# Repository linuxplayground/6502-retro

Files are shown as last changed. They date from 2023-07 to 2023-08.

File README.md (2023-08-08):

# 6502-Retro!

Inspired by the Z80-Retro! see: [https://github.com/z80-retro](https://github.com/z80-retro)
I decided to see if I could put together a small 6502 based project with a similar
design philosphy.  The main goals of the project are:

1. The base board must be no larger than 100mm x 100mm to leverage the cheaper
    manufacturing options.
2. The base board must provide all required functionality to be minimially operational.
3. Daughter boards will provide additional peripherals such as Graphics and Audio

## Base Board

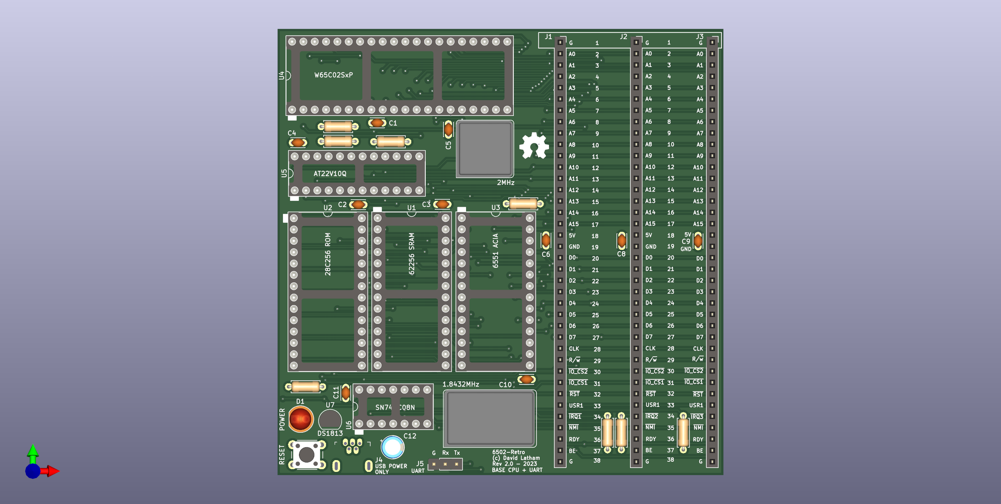
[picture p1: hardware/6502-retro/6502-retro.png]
Base Board


You can find the hardware 
[schematic](./hardware/6502-retro/6502-retro.pdf) and gerber files for the base 
board in [hardware/6502-retro](./hardware/6502-retro/).

## Expansion Boards

This project contains two expansion boards.

### NOTE !!

One of the expansion slots (J1) is too close to the BAUD RATE Oscilator on the 
base board.  It can be used for manual jumper wires maybe, but I would not risk
putting a card in there as the solder joints on the back of the card will short
against the metal oscilator can for the baud rate clock.

### F18A (TMS9918A FPGA)

The F18A from [dnotq](https://dnotq.io/f18a/intro.html) is mounted with some
glue logic on an expansion board.  It provides all the same features as the 
TMS9918A VDP along with some additional enhancments that can be accessed in
software.

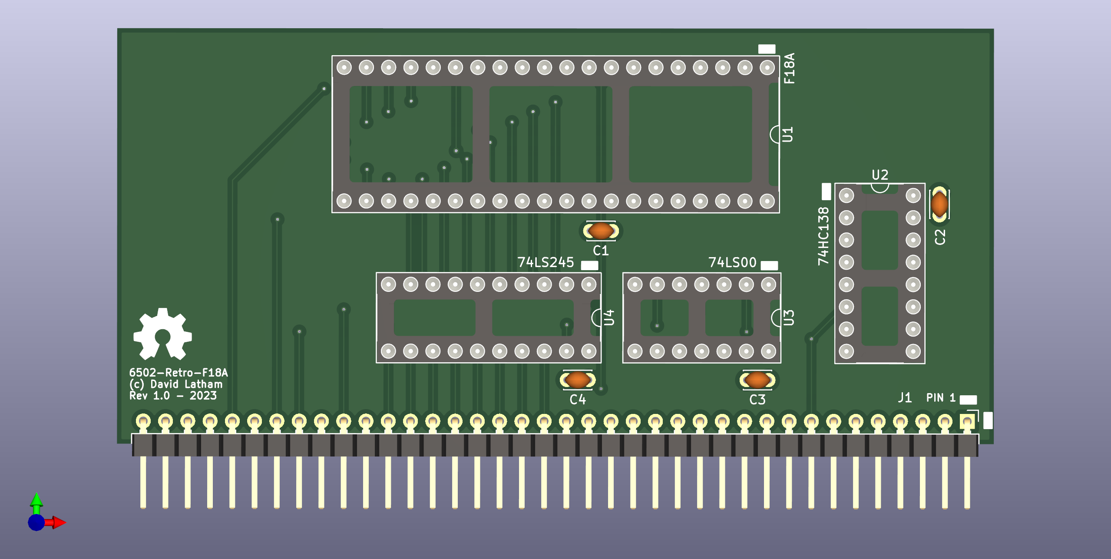
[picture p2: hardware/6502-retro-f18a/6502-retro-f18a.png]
F18A Board


You can find the hardware [schematic here.](./hardware/6502-retro-f18a/6502-retro-f18a.pdf)

### General Purpose IO + PS/2

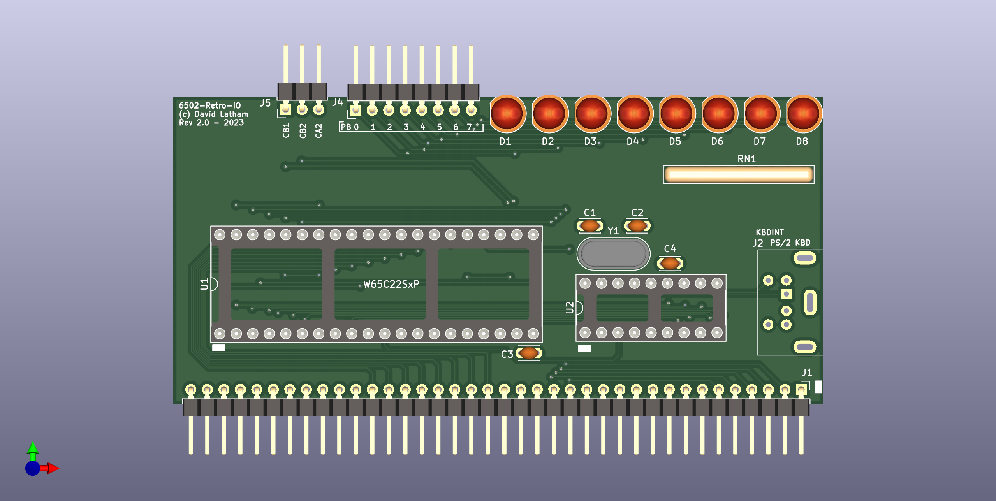
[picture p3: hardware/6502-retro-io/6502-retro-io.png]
GPIO + PS/2


You can find the hardware [schematic here.](./hardware/6502-retro-io/6502-retro-io.pdf)

Note: PS/2 Support is designed for the [PERIBOARD-409 P - Mini PS/2 keyboard](https://perixx.com/products/ps2-mini-keyboard)

This board has a "sign-on" routine that's handled in the PIC16F628A
microcontroller.  The code for the MCU is included [here](./pic16f628a/)

The more generic / standard PS/2 Keyboards will require the MCU code to be
altered.

## Memory Map

The memory map is given by an AT22v10Q PLD which provides ranges in the table below.  These values are also defined in [6502-retro-rom.cfg](./software/6502-retro-rom.cfg)

|Range |Description |Size | Decoder Pins| Comments
|--- |--- |--- |--- |---
|0000-00FF |Zero Page |0x100  | |
|0100-0200 |Stack |0x100  | |
|0200-0FFF |SYSRAM |0xE00  | |
|1000-7EFF |RAM |0x6F00 | |
| | | | |
|7F00-7F10 |UNMAPPED |0x16 | |
|7F10-7F1F |FREE |0x16 | IOCS1 + A4  | IOCS1 is clock qualified
|7F20-7F2F |ACIA |0x16 | IOCS1 + A5  |
|7F30-7F3F |UNMAPPED |0x16 | |
|7F40-7F4F |F18A / TMS9918A |0x16 | IOCS1 + A6  |
|7F50-7F8F |UNAMPPED |0x64 | |
|7F90-7F90 |VIA |0x16 | IOCS2 + A4  | IOCS2 is not clock qualified
|7FA0-7FAF |FREE |0x16 | IOCS2 + A5  |
|7FB0-7FBF |UMAPPED |0x16 | | 
|7FC0-7FCF |FREE |0x16 | IOCS2 + A6  |
|7FD0-7FEF |UNMAPPED |0x64 | |

* IOCS1 is only active when phi2 is HIGH in the shown address ranges.
* IOCS2 is active in the shown address ranges without any influence by phi2.

See the [PLD Code](./pld/6502-RETRO-PLD.PLD) for the WinCUPL design file.

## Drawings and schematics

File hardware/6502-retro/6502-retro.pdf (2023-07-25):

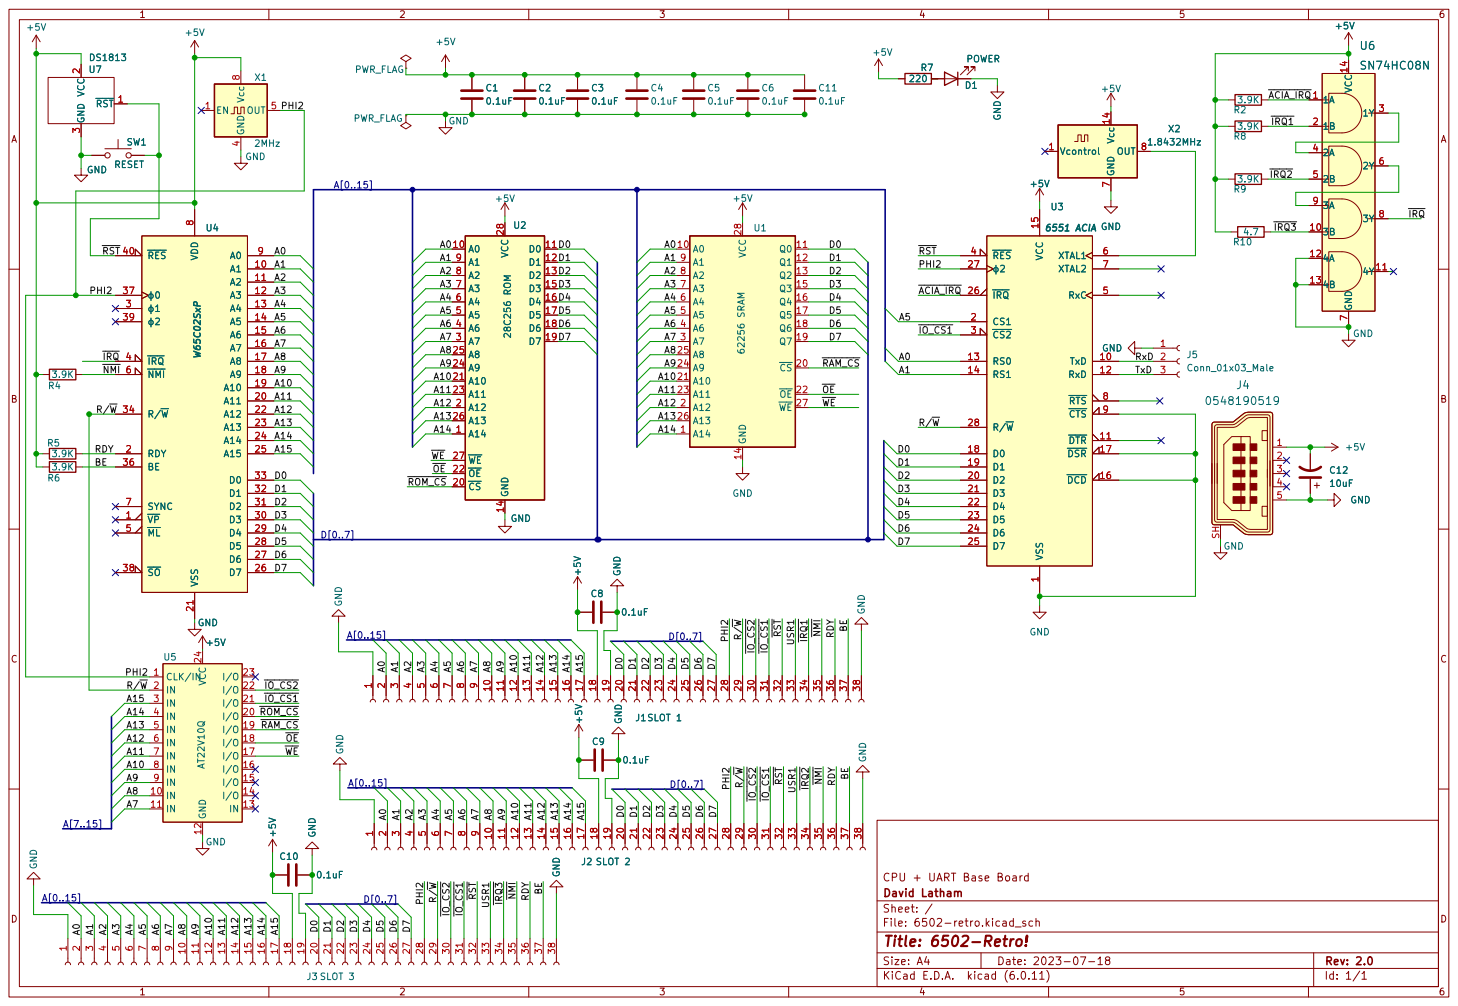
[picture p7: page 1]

CPU + UART Base Board +5V C9

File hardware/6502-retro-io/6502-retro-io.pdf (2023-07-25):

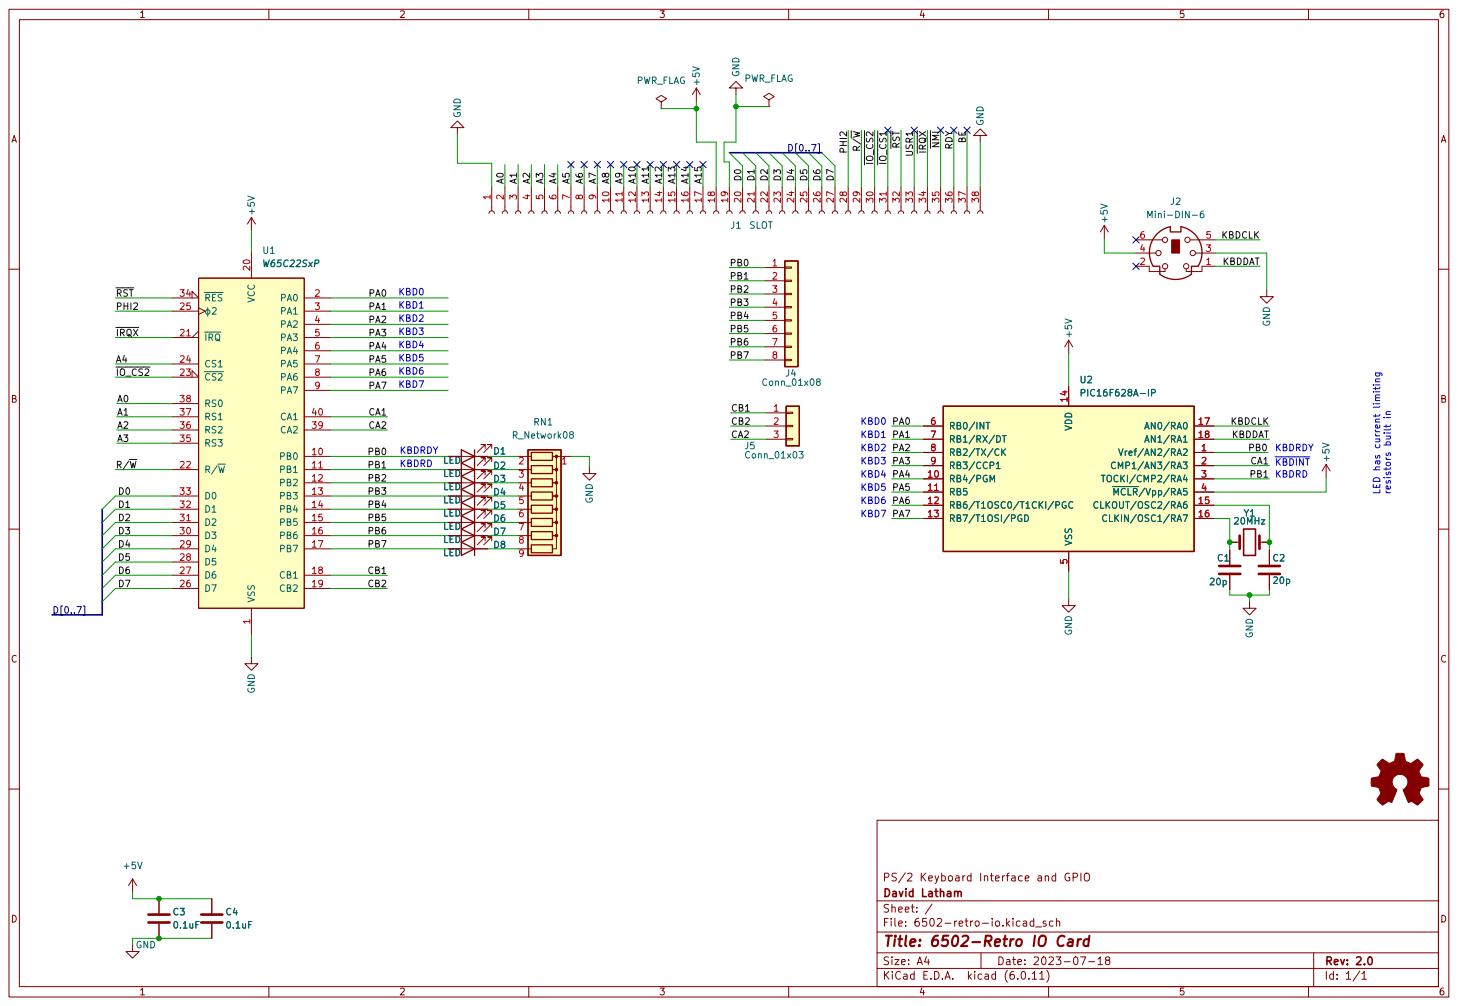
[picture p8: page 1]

5 RB0/INT 6 RB1/RX/DT 7 RB2/TX/CK 8 RB3/CCP1 9 U2PIC16F628A-IP D6

5 RB0/INT 6 RB1/RX/DT 7 RB2/TX/CK 8 RB3/CCP1 9

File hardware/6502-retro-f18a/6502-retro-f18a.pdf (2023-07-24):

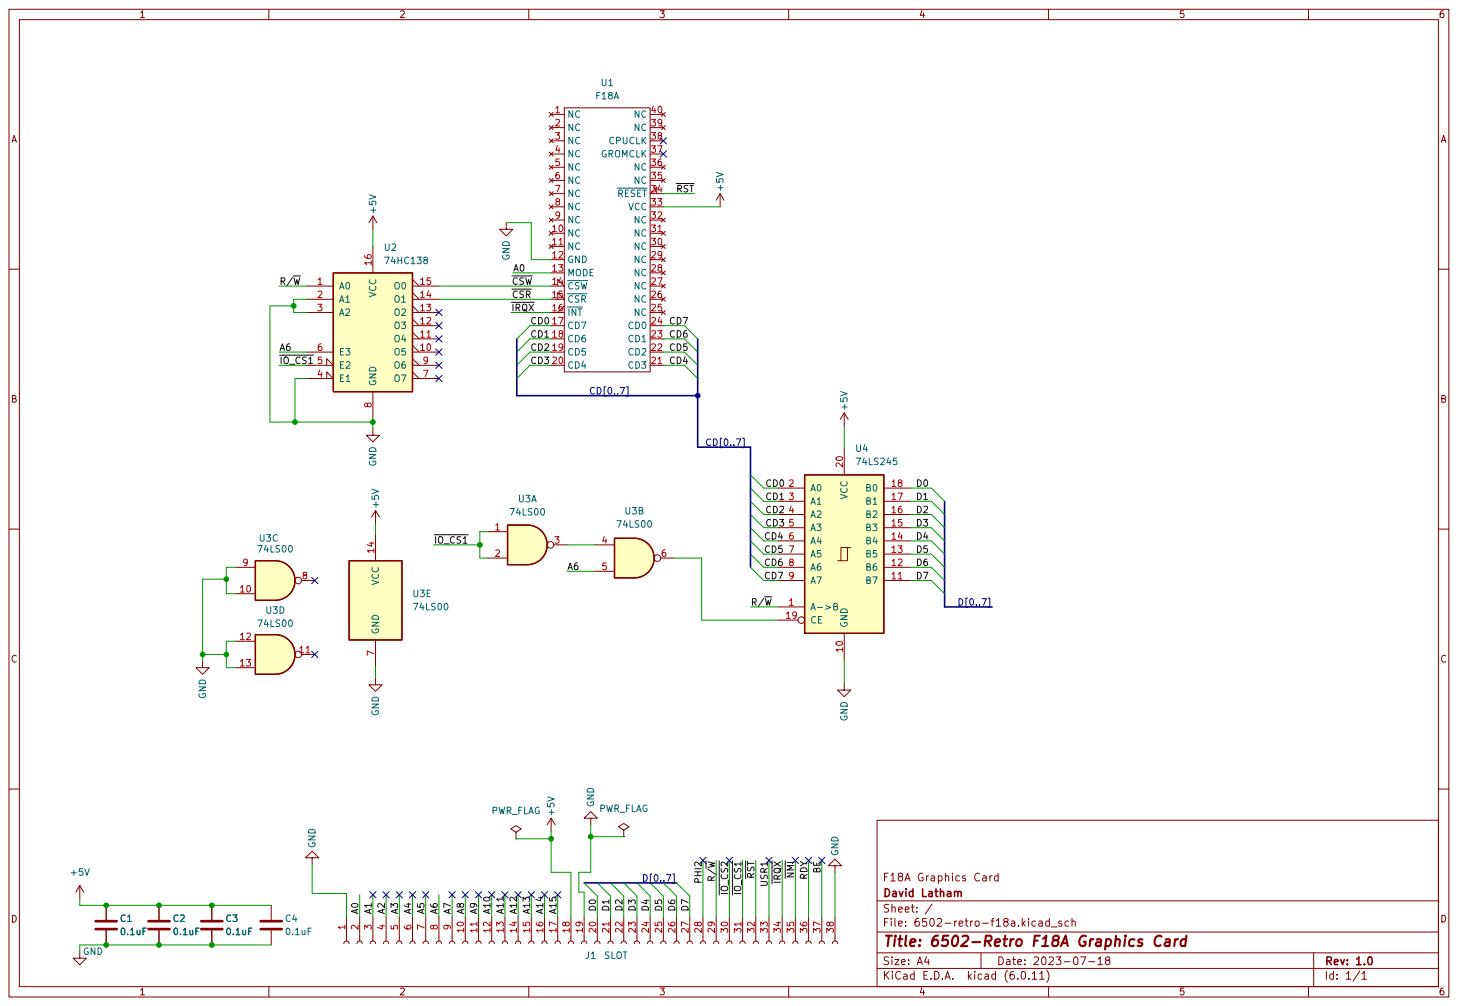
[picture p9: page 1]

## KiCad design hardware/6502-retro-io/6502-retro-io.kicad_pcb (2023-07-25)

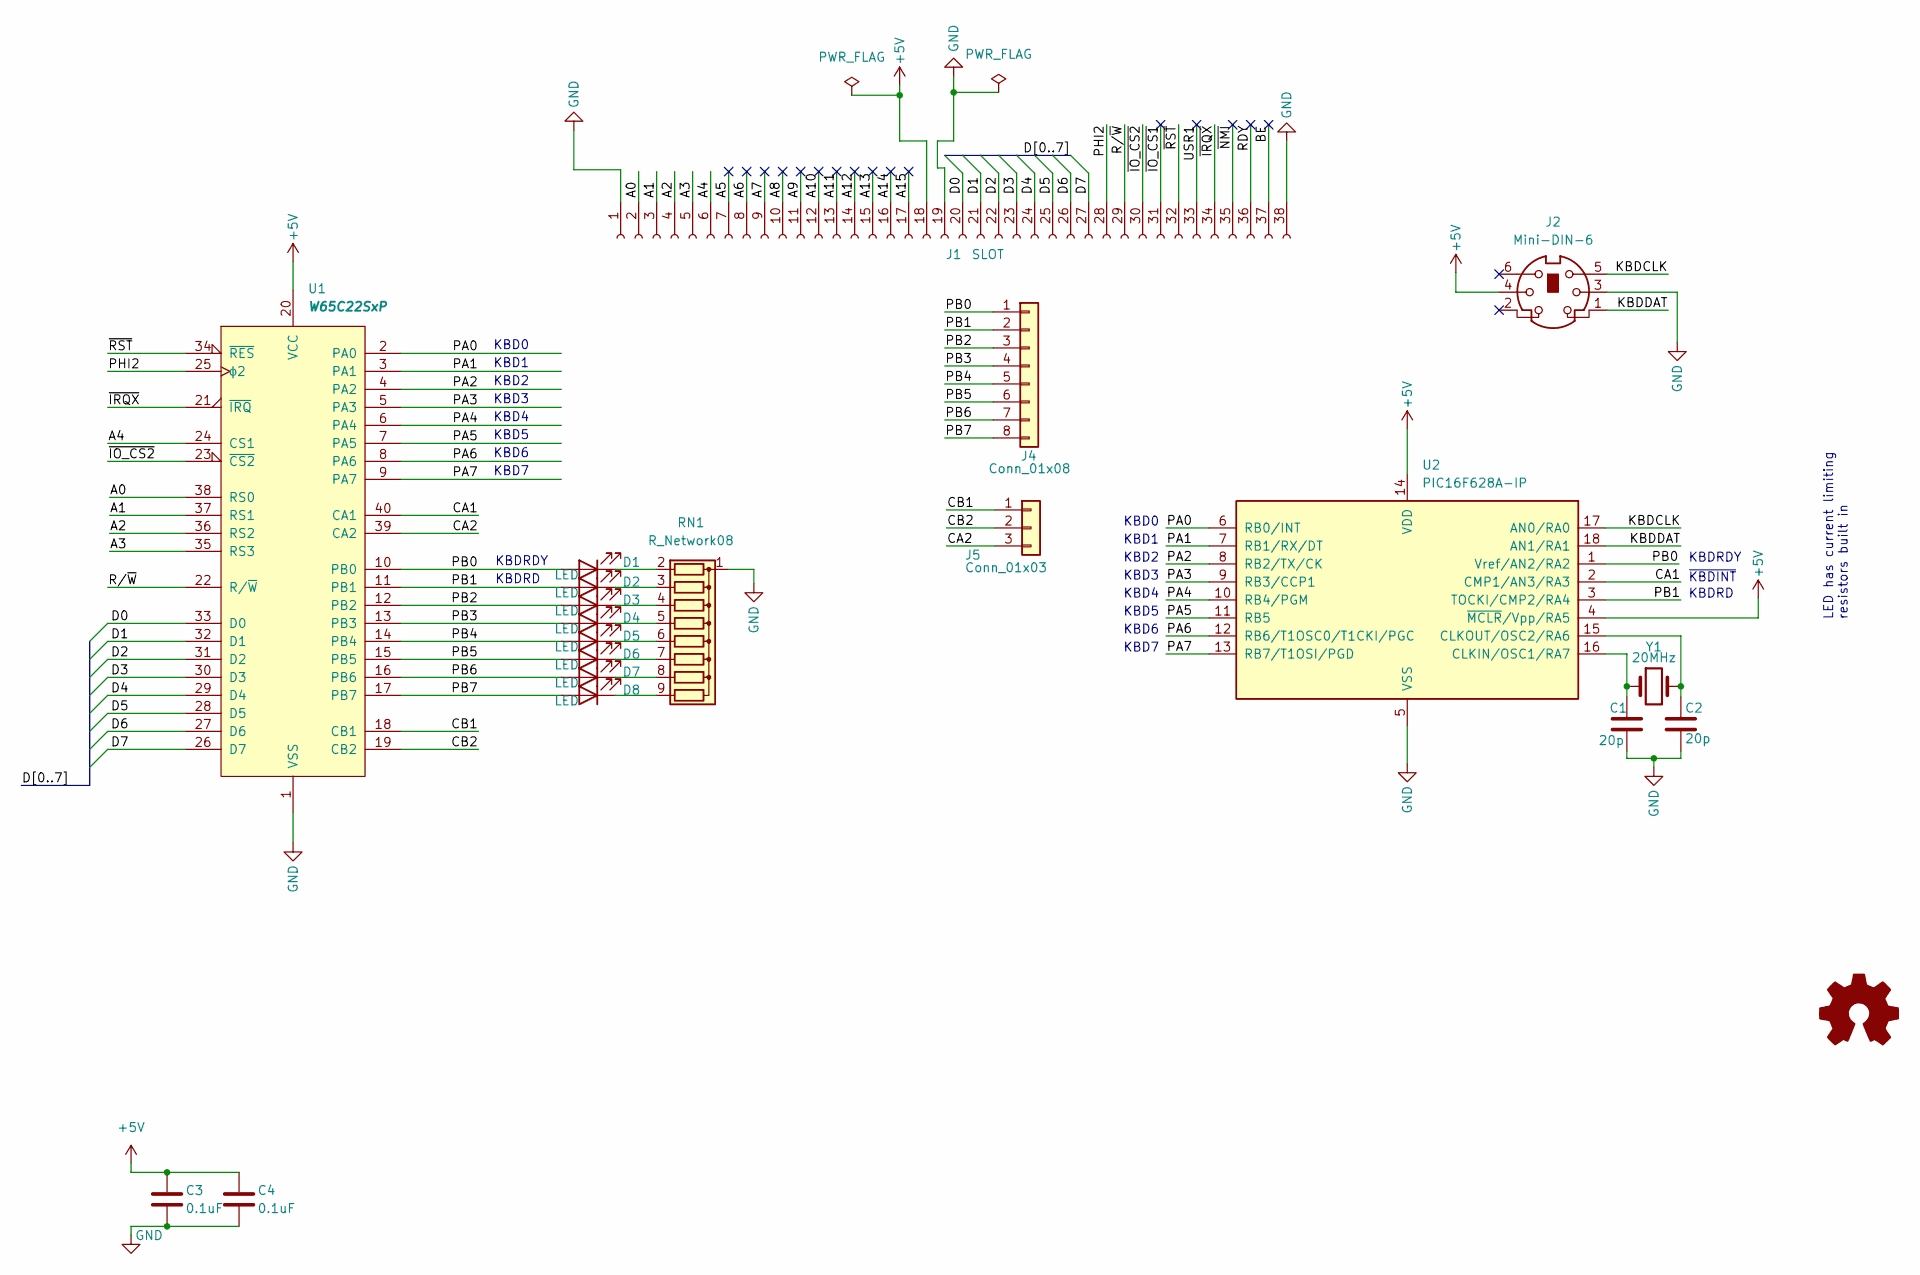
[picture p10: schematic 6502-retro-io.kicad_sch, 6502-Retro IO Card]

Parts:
C1, C2: 20p; C_Disc_D3.0mm_W2.0mm_P2.50mm
C3, C4: 0.1uF; C_Disc_D3.0mm_W2.0mm_P2.50mm
D1, D2, D3, D4, D5, D6, D7, D8: LED; LED_D5.0mm
J1: SLOT; PinHeader_1x38_P2.54mm_Horizontal
J2: Mini-DIN-6; Connector_Mini-DIN_Female_6Pin_2rows
J4: Conn_01x08; PinHeader_1x08_P2.54mm_Horizontal
J5: Conn_01x03; PinHeader_1x03_P2.54mm_Horizontal
RN1: R_Network08; R_Array_SIP9
U1: W65C22SxP; DIP-40_W15.24mm_Socket
U2: PIC16F628A-IP; DIP-18_W7.62mm_Socket
Y1: 20MHz; Crystal_HC18-U_Vertical

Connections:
+5V: C3.1, C4.1, J1.18, J2.4, U1.20 (VCC), U2.4 (~MCLR/Vpp/RA5), U2.14 (VDD)
/A0: J1.2, U1.38 (RS0)
/A1: J1.3, U1.37 (RS1)
/A2: J1.4, U1.36 (RS2)
/A3: J1.5, U1.35 (RS3)
/A4: J1.6, U1.24 (CS1)
/A5: J1.7
/A6: J1.8
/A7: J1.9
/A8: J1.10
/A9: J1.11
/A10: J1.12
/A11: J1.13
/A12: J1.14
/A13: J1.15
/A14: J1.16
/A15: J1.17
/BE: J1.37
/CA1: U1.40 (CA1), U2.2 (CMP1/AN3/RA3)
/CA2: J5.3, U1.39 (CA2)
/CB1: J5.1, U1.18 (CB1)
/CB2: J5.2, U1.19 (CB2)
/D0: J1.20, U1.33 (D0)
/D1: J1.21, U1.32 (D1)
/D2: J1.22, U1.31 (D2)
/D3: J1.23, U1.30 (D3)
/D4: J1.24, U1.29 (D4)
/D5: J1.25, U1.28 (D5)
/D6: J1.26, U1.27 (D6)
/D7: J1.27, U1.26 (D7)
/KBDCLK: J2.5, U2.17 (AN0/RA0)
/KBDDAT: J2.1, U2.18 (AN1/RA1)
/PA0: U1.2 (PA0), U2.6 (RB0/INT)
/PA1: U1.3 (PA1), U2.7 (RB1/RX/DT)
/PA2: U1.4 (PA2), U2.8 (RB2/TX/CK)
/PA3: U1.5 (PA3), U2.9 (RB3/CCP1)
/PA4: U1.6 (PA4), U2.10 (RB4/PGM)
/PA5: U1.7 (PA5), U2.11 (RB5)
/PA6: U1.8 (PA6), U2.12 (RB6/T1OSC0/T1CKI/PGC)
/PA7: U1.9 (PA7), U2.13 (RB7/T1OSI/PGD)
/PB0: D1.2 (A), J4.1, U1.10 (PB0), U2.1 (Vref/AN2/RA2)
/PB1: D2.2 (A), J4.2, U1.11 (PB1), U2.3 (TOCKI/CMP2/RA4)
/PB2: D3.2 (A), J4.3, U1.12 (PB2)
/PB3: D4.2 (A), J4.4, U1.13 (PB3)
/PB4: D5.2 (A), J4.5, U1.14 (PB4)
/PB5: D6.2 (A), J4.6, U1.15 (PB5)
/PB6: D7.2 (A), J4.7, U1.16 (PB6)
/PB7: D8.2 (A), J4.8, U1.17 (PB7)
/PHI2: J1.28, U1.25 (ϕ2)
/RDY: J1.36
/R/~W: J1.29, U1.22 (R/~W)
/USR1: J1.33
/~IO_CS1: J1.31
/~IO_CS2: J1.30, U1.23 (~CS2)
/~IRQX: J1.34, U1.21 (~IRQ)
/~NMI: J1.35
/~RST: J1.32, U1.34 (~RES)
GND: C1.2, C2.2, C3.2, C4.2, J1.1, J1.19, J1.38, J2.3, RN1.1 (common), U1.1 (VSS), U2.5 (VSS)
unnamed: C1.1, U2.16 (CLKIN/OSC1/RA7), Y1.1
unnamed: C2.1, U2.15 (CLKOUT/OSC2/RA6), Y1.2
unnamed: D1.1 (K), RN1.2 (R1)
unnamed: D2.1 (K), RN1.3 (R2)
unnamed: D3.1 (K), RN1.4 (R3)
unnamed: D4.1 (K), RN1.5 (R4)
unnamed: D5.1 (K), RN1.6 (R5)
unnamed: D6.1 (K), RN1.7 (R6)
unnamed: D7.1 (K), RN1.8 (R7)
unnamed: D8.1 (K), RN1.9 (R8)

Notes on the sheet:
KBD6
KBD2
KBD4
KBD0
~{KBDINT}
KBDRDY
KBD7
KBD1
KBDRD
KBD3
KBD5
LED has current limiting resistors built in

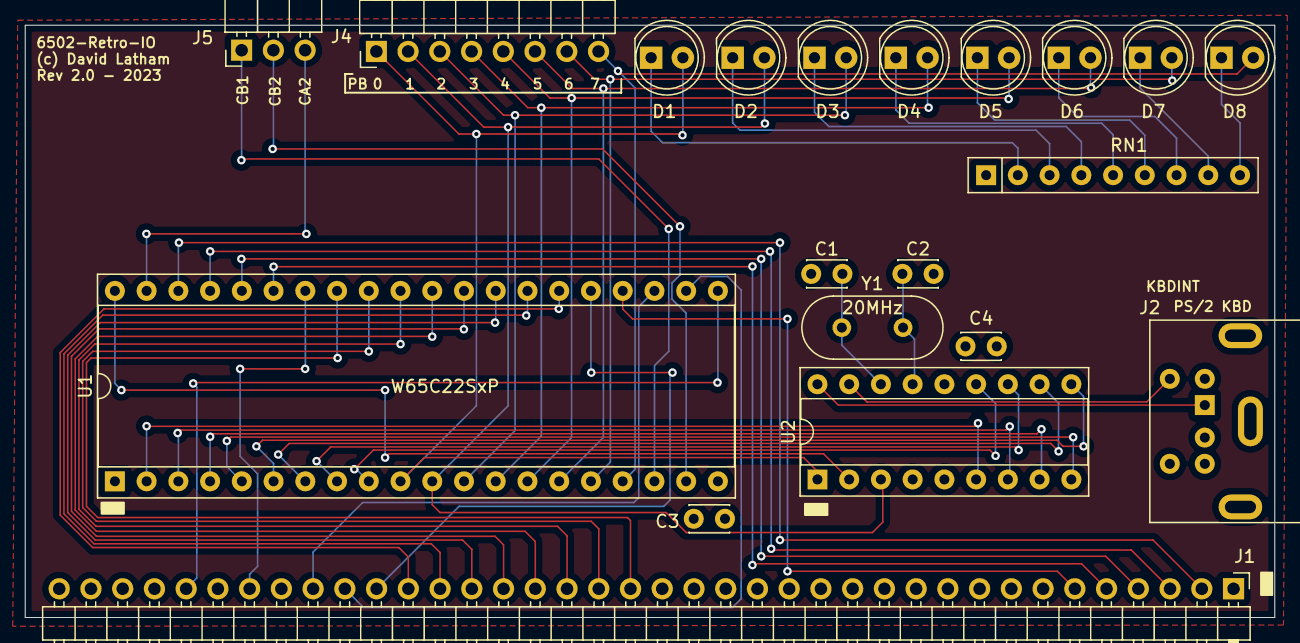
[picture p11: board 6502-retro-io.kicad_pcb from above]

Board: 4 copper layers, 100.0 x 47.4 mm, 20 parts (0 on the bottom side), 52 nets.

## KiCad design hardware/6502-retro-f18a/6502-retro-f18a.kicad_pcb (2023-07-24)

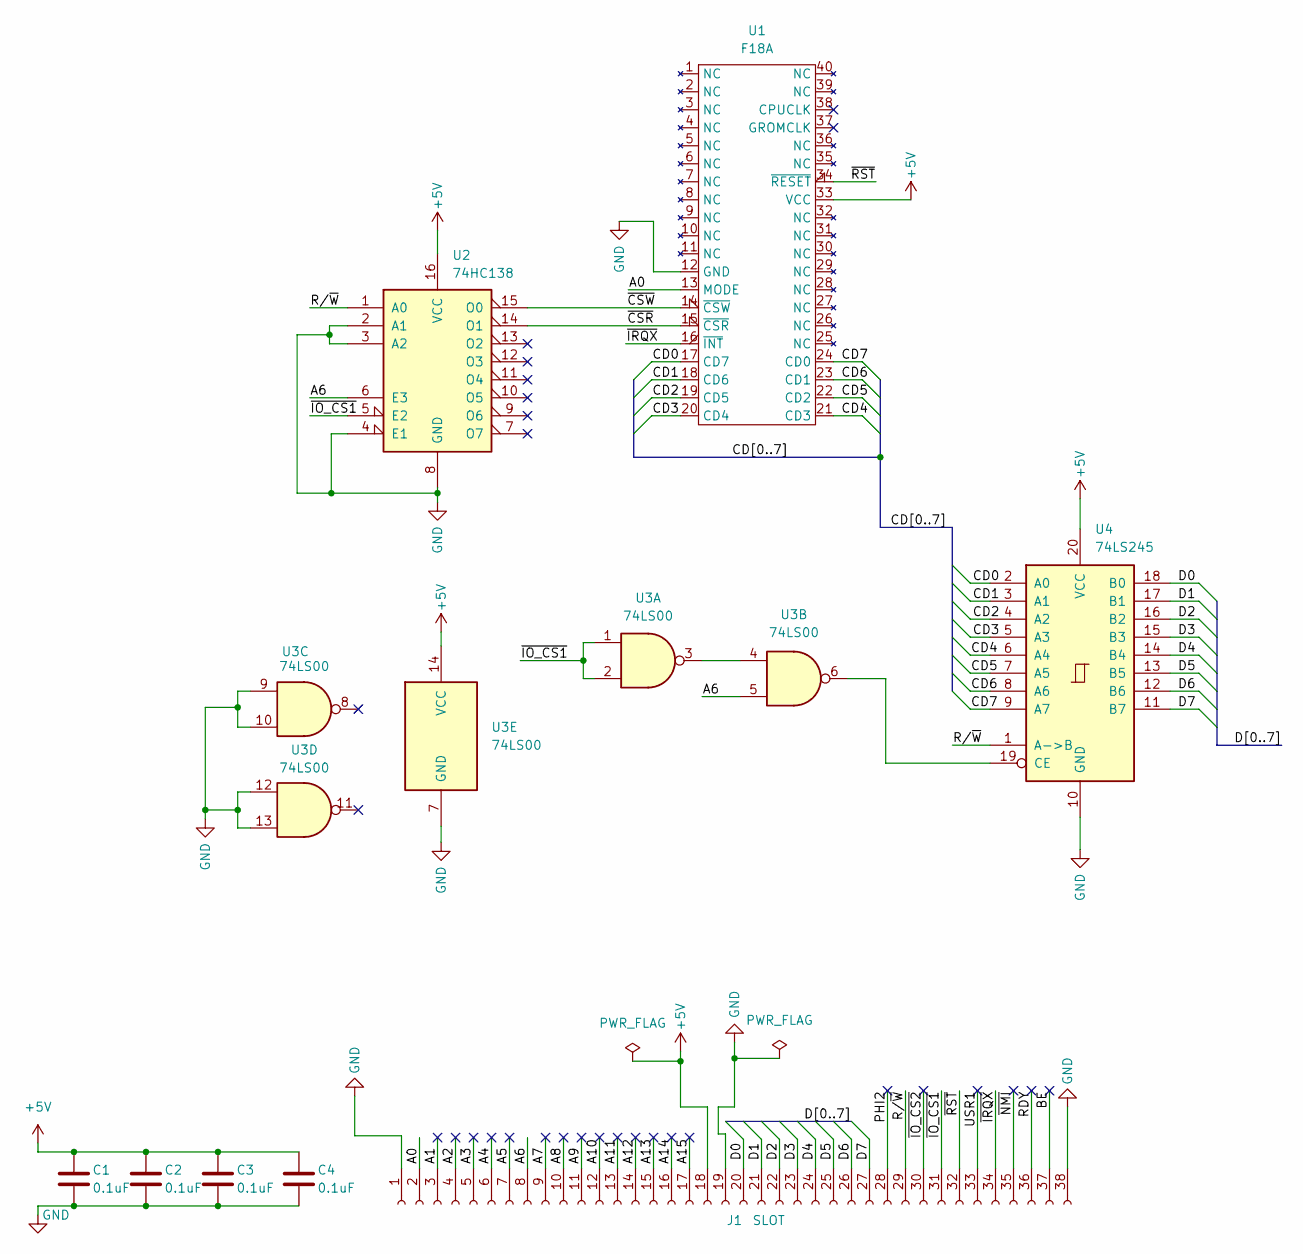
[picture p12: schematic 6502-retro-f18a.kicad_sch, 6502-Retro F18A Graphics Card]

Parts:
C1, C2, C3, C4: 0.1uF; C_Disc_D3.0mm_W2.0mm_P2.50mm
J1: SLOT; PinHeader_1x38_P2.54mm_Horizontal
U1: F18A; DIP-40_W15.24mm_Socket
U2: 74HC138; DIP-16_W7.62mm_Socket
U3: 74LS00
U4: 74LS245; DIP-20_W7.62mm_Socket

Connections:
+5V: C1.1, C2.1, C3.1, C4.1, J1.18, U1.33 (VCC), U2.16 (VCC), U3.14 (VCC), U4.20 (VCC)
/A0: J1.2, U1.13 (MODE)
/A1: J1.3
/A2: J1.4
/A3: J1.5
/A4: J1.6
/A5: J1.7
/A6: J1.8, U2.6 (E3), U3.5
/A7: J1.9
/A8: J1.10
/A9: J1.11
/A10: J1.12
/A11: J1.13
/A12: J1.14
/A13: J1.15
/A14: J1.16
/A15: J1.17
/BE: J1.37
/CD0: U1.17 (CD7), U4.2 (A0)
/CD1: U1.18 (CD6), U4.3 (A1)
/CD2: U1.19 (CD5), U4.4 (A2)
/CD3: U1.20 (CD4), U4.5 (A3)
/CD4: U1.21 (CD3), U4.6 (A4)
/CD5: U1.22 (CD2), U4.7 (A5)
/CD6: U1.23 (CD1), U4.8 (A6)
/CD7: U1.24 (CD0), U4.9 (A7)
/D0: J1.20, U4.18 (B0)
/D1: J1.21, U4.17 (B1)
/D2: J1.22, U4.16 (B2)
/D3: J1.23, U4.15 (B3)
/D4: J1.24, U4.14 (B4)
/D5: J1.25, U4.13 (B5)
/D6: J1.26, U4.12 (B6)
/D7: J1.27, U4.11 (B7)
/PHI2: J1.28
/RDY: J1.36
/R/~W: J1.29, U2.1 (A0), U4.1 (A->B)
/USR1: J1.33
/~CSR: U1.15 (~CSR), U2.14 (O1)
/~CSW: U1.14 (~CSW), U2.15 (O0)
/~IO_CS1: J1.31, U2.5 (E2), U3.1, U3.2
/~IO_CS2: J1.30
/~IRQX: J1.34, U1.16 (~INT)
/~NMI: J1.35
/~RST: J1.32, U1.34 (~RESET)
unnamed: U3.3, U3.4
unnamed: U3.6, U4.19 (CE)

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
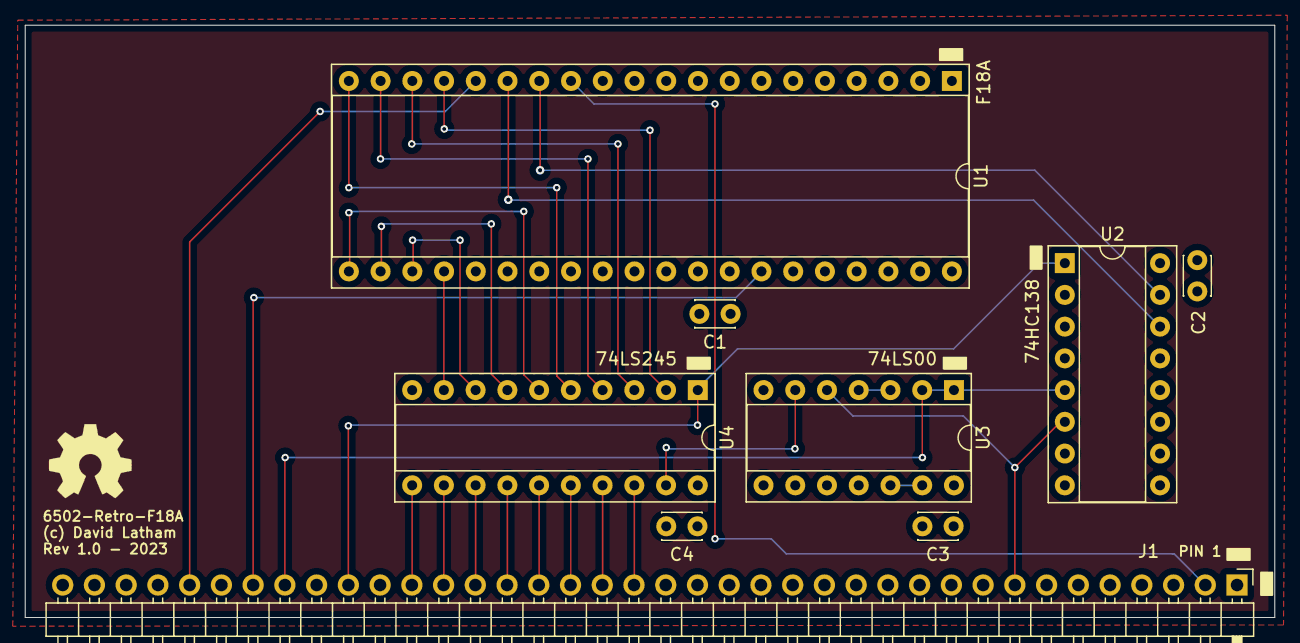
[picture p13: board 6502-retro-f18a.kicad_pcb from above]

Board: 4 copper layers, 100.0 x 47.4 mm, 9 parts (0 on the bottom side), 28 nets.

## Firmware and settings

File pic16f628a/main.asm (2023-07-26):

; PS/2 Keyboard Controller (for PIC16F627A)
;
; Troy's HBC-56 homebrew computer    
;
; Copyright (c) 2021 Troy Schrapel
;
; This code is licensed under the MIT license
;
; https://github.com/visrealm/hbc-56

PROCESSOR 16F628A

#include <xc.inc>

CONFIG  FOSC = HS             ; Oscillator Selection bits (HS oscillator: High-speed crystal/resonator on RA6/OSC2/CLKOUT and RA7/OSC1/CLKIN)
CONFIG  WDTE = OFF            ; Watchdog Timer Enable bit (WDT disabled)
CONFIG  PWRTE = OFF           ; Power-up Timer Enable bit (PWRT disabled)
CONFIG  MCLRE = ON            ; RA5/MCLR/VPP Pin Function Select bit (RA5/MCLR/VPP pin function is MCLR)
CONFIG  BOREN = OFF           ; Brown-out Detect Enable bit (BOD disabled)
CONFIG  LVP = OFF             ; Low-Voltage Programming Enable bit (RB4/PGM pin has digital I/O function, HV on MCLR must be used for programming)
CONFIG  CPD = OFF             ; Data EE Memory Code Protection bit (Data memory code protection off)
CONFIG  CP = OFF              ; Flash Program Memory Code Protection bit (Code protection off)

;                          PIC16F627A
;                            PINOUT
;                         +----------+
;     DAT_RDY (O) - RA2 ==| 1     18 |== RA1 - PS/2 DATA  (I)
;        _INT (O) - RA3 ==| 2     17 |== RA0 - PS/2 CLOCK (I)
;   NEXT_CODE (I) - RA4 ==| 3     16 |== RA7 - XTAL 1
;      _RESET (I) - RA5 ==| 4     15 |== RA6 - XTAL 2
;                   GND ==| 5     14 |== VCC
;   SCANCODE0 (O) - RB0 ==| 6     13 |== RB7 - SCANCODE7 (O)
;   SCANCODE1 (O) - RB1 ==| 7     12 |== RB6 - SCANCODE6 (O)
;   SCANCODE2 (O) - RB2 ==| 8     11 |== RB5 - SCANCODE5 (O)
;   SCANCODE3 (O) - RB3 ==| 9     10 |== RB4 - SCANCODE4 (O)
;                         +----------+
;
; NEXT_CODE - Positive edge-triggered input which triggers the controller
;             to output the next scancode. DAT_RDY becomes low until that next
;             scancode is ready on RB
     
#define CLOCK_PIN	RA0
#define CLOCK_IO	TRISA0
#define DATA_PIN	RA1
#define DATA_IO		TRISA1
#define DAT_RDY_PIN	RA2
#define DAT_RDY_IO	TRISA2
#define _INT_PIN	RA3
#define _INT_IO		TRISA3

CPUFREQ		equ	20000000	    ; CPU frequency (20MHz)
DELAY_US_COUNT	equ	(CPUFREQ / 10000000)
BYTE_BITS	equ	8
BUFFER_BITS	equ	4		    ; 2^4 bytes in buffer
BUFFER_SIZE	equ	(1 << BUFFER_BITS)  ; (16)
BUFFER_MASK     equ	(BUFFER_SIZE - 1)   ; 0x0F
PS2_TEST_PASS	equ	0xAA

; ------------------------------------------------------------------------------
; udata - variables
; ------------------------------------------------------------------------------
PSECT udata
delay_us:	    ds 1
delay_us_counter:   ds 1    
buffer:		    ds BUFFER_SIZE	; circular buffer
bufferHead:	    ds 1		; circular buffer head pointer
bufferTail:	    ds 1		; circular buffer tail pointer
rxByteTmp:	    ds 1		; temporary storage for received byte
txByteTmp:	    ds 1		; temporary storage for sent byte
loopVar:	    ds 1		; looping variable
    
; ------------------------------------------------------------------------------
; bank0 - Switch to bank0 
; ------------------------------------------------------------------------------
bank0 macro
    bcf	    RP0	    ; we don't use bank 1/2, so only need to clear RP0
    bsf	    T0IE    ; enable interrupt
endm

; ------------------------------------------------------------------------------
; bank1 - Switch to bank1 
; ------------------------------------------------------------------------------
bank1 macro
    bcf	    T0IE    ; disable interrupt
    bsf	    RP0	    ; we don't use bank 1/2, so only need to set RP0
endm
    
; ------------------------------------------------------------------------------
; skipIfQueueNotEmpty - Skip the next instruction if the queue is not empty
; ------------------------------------------------------------------------------
skipIfQueueNotEmpty macro
    movf    bufferTail,w
    xorwf   bufferHead,w    ; xor rather than subtract to avoid setting carry
    btfsc   ZERO
endm
    
; ------------------------------------------------------------------------------
; clearOutput - Clear the output register
; ------------------------------------------------------------------------------
clearOutput macro
    clrf    PORTB
endm

; ------------------------------------------------------------------------------
; writeOutput - Write W to the output register
; ------------------------------------------------------------------------------
writeOutput macro
    movwf   PORTB
endm

; ------------------------------------------------------------------------------
; resetTimer
; ------------------------------------------------------------------------------
resetTimer macro
    clrf    TMR0    ; Set timer to 255 (one increment will trigger interrupt)
    decf    TMR0
    bcf	    T0IF    ; Clear Timer0 interrupt flag
endm

; ------------------------------------------------------------------------------
; skipIfOutputEmpty - Skip the next instruction if the output is empty
; ------------------------------------------------------------------------------
skipIfOutputEmpty macro
    movf    PORTB,w		    ; check current OE value
    btfss   ZERO		    ; if not zero
endm

    
PSECT resetVec,class=CODE,delta=2
; ------------------------------------------------------------------------------
; resetVec - entry point
; ------------------------------------------------------------------------------
resetVec:
    goto main

PSECT intVec,class=CODE,delta=2
; ------------------------------------------------------------------------------
; intVec - interrupt handler
; ------------------------------------------------------------------------------
intVec:
    bcf DAT_RDY_PIN		; clear data ready
    clearOutput 		; clear output
    
    ; set up timer again
    resetTimer
    retfie
  
PSECT code
; ------------------------------------------------------------------------------
; main - program entry
; ------------------------------------------------------------------------------
main:
    call    init		; initialise the registers
    call    waitForKbSelfTest	; wait for the keyboard

    resetTimer
    bsf	    GIE			; Global interrupt enable
    call    loop		; enter the main loop
    
; ------------------------------------------------------------------------------
; init - initialise the MCU registers
; ------------------------------------------------------------------------------
init:
    clrf    STATUS

    bank0
    clrf    PORTA	  ; Initialize GPIO by clearing output
    clrf    PORTB	  ; Initialize GPIO by clearing output
    bsf	    _INT_PIN	  ; Turn off interrupt out
    movlw   CMCON_CM_MASK ; Turn comparators off
    movwf   CMCON

    bank1
    bcf	    GIE		  ; Global interrupt disable    
    clrf    TRISA	  ; Initialize GPIO by setting all pins as output
    clrf    TRISB         ; Initialize GPIO by setting all pins as output

    bsf	    CLOCK_IO      ; set Clock as floating (input)
    bsf	    DATA_IO       ; set Data as floating (input)
    
    bsf	    TRISA4	  ; Timer0 clock pin (input)
    bsf	    TRISA5	  ; Reset pin (input)
    
    bsf	    T0CS	  ; Timer0 external clock mode (counter mode)
    bcf	    T0SE	  ; Timer0 increment on rising edge
    bcf	    T0IF	  ; Clear Timer0 interrupt flag
    bank0

    clrf    bufferHead	  ; clear variables
    clrf    bufferTail
    clrf    rxByteTmp
    clrf    txByteTmp
    
    return

; ------------------------------------------------------------------------------
; waitForKbSelfTest - Wait for Kb self test code and reply
; ------------------------------------------------------------------------------
; My Perixx PERIBOARD-409 releatedly sends 0xAA until a response is received
; from the host. This subroutine waits for 0xAA and sends a response.
; ------------------------------------------------------------------------------
waitForKbSelfTest:
    movlw   255
    call    delayUs
    bsf     DAT_RDY_PIN
    call    readByte		    ; read a byte into rxByteTmp
    movf    rxByteTmp,w
    xorlw   PS2_TEST_PASS	    ; Self-test pass?
    btfss   ZERO		    ; loop again if not zero
    goto    waitForKbSelfTest
    

    movlw   200
    call    delayUs
    
    call    pullClockUp		    ; initiate a send
    call    pullDataUp
    movlw   40
    call    delayUs
    call    pullClockDown
    movlw   200
    call    delayUs
    call    pullDataDown
    call    releaseClock  
    bcf	    DAT_RDY_PIN
    
    ; Note: due to my keyboard not sending clock signals??? we just wait
    ;       and return
    
    nop
    nop  
    call    pullDataUp
    movlw   180
    call    delayUs
    call    releaseData

    call    longDelay
    
    return


; ------------------------------------------------------------------------------
; loop - main program loop
; ------------------------------------------------------------------------------
loop:
    btfsc   DAT_RDY_PIN		    ; skip if data is ready... already
    goto    checkForKeyboardInput
    
    call    qPopFront		    ; get the received scancode
    btfsc   ZERO		    ; was queue empty?
    goto    checkForKeyboardInput
    
    writeOutput 		    ; output it
    
    bsf	    DAT_RDY_PIN		    ; data is now ready to be read

    skipIfQueueNotEmpty
    bsf	    _INT_PIN		    ; clear interrupt
    
checkForKeyboardInput:
    btfsc   CLOCK_PIN		    ; check if clock is low
    goto    loop		    ; if it's not, skip the read

    call    readByte
    call    qPushBack
  
dataIsReady:  
    bcf	    _INT_PIN		    ; Interrupt

    movlw   100
    call    delayUs

    goto loop
    
  
; ------------------------------------------------------------------------------
; qPushBack - Push data to end of queue
; ------------------------------------------------------------------------------
; Inputs: rxByteTmp - value to push
; ------------------------------------------------------------------------------
qPushBack:
    movlw   buffer		    ; set up FSR to buffer tail
    bcf	    CARRY
    addwf   bufferTail,w
    movwf   FSR

    movf    rxByteTmp,w		    ; write rxByteTmp to buffer
    movwf   INDF

    incf    bufferTail		    ; increment bufferTail pointer
    movlw   BUFFER_MASK		    ; roll around if pointer
    andwf   bufferTail,f            ; past end
    return
    
; ------------------------------------------------------------------------------
; qPopFront - Pop data from the front of the queue
; ------------------------------------------------------------------------------
; Returns: Value returned in W
;	   0 if queue is empty
; ------------------------------------------------------------------------------
qPopFront:
    clrw
    skipIfQueueNotEmpty		    ; return if queue is empty
    return    

    movlw   buffer		    ; set up FSR to buffer head
    bcf	    CARRY
    addwf   bufferHead,w
    movwf   FSR

    incf    bufferHead		    ; increment bufferHead pointer
    movlw   BUFFER_MASK		    ; roll around if pointer
    andwf   bufferHead,f	    ; past end

    movf    INDF,w		    ; output value to W
    return
    
; ------------------------------------------------------------------------------
; sendByte - send a byte of data over PS/2 interface
; ------------------------------------------------------------------------------
; Inputs: W - value to send
; ------------------------------------------------------------------------------
sendByte:
    movwf   txByteTmp		    ; set up temp value
    
    call    pullClockDown	    ; pull the clock line down
    movlw   25			    ; wait 100us
    call    delayUs
    call    pullDataDown
    call    releaseClock    
    nop
    nop  
    call    pullDataUp		    ; data high
    
    movlw   BYTE_BITS		    ; set up loop variable (8 bits)
    movwf   loopVar

sendBitLoop:			    ; send a bit
    rrf	rxByteTmp		    ; rotate the value to get bit 0 in CARRY
    
    call    waitForClockLow	    ; wait for clock low
    call    pullDataDown	    
    btfsc   CARRY		    ; skip if CARRY is 0
    call    pullDataUp
    call    waitForClockHigh    
    
    decfsz  loopVar		    ; next bit?
    goto    sendBitLoop
    call    releaseData
    return
    
; ------------------------------------------------------------------------------
; readByte - read a byte from the PS/2 interface
; ------------------------------------------------------------------------------
; Returns: rxByteTmp - value read
; ------------------------------------------------------------------------------
readByte:
    call    waitForClockLow ; read start bit
    clrf    rxByteTmp
    
    movlw   BYTE_BITS	    ; set up loop (8 bits)
    movwf   loopVar
    
    call    waitForClockHigh
readBitLoop:		    ; read a bit
    bcf	    CARRY           ; clear carry
    call    waitForClockLow 
    btfsc   DATA_PIN	    ; skip if DATA is 0
    bsf	    CARRY	    ; set CARRY (if data 1)
    call    waitForClockHigh
    
    rrf	    rxByteTmp	    ; rotate CARRY into temp value
    
    decfsz  loopVar	    ; next bit?
    goto    readBitLoop
    return
    
; ------------------------------------------------------------------------------
; waitForClockHigh - loops until the CLOCK input pin is high
; ------------------------------------------------------------------------------
waitForClockHigh:
    btfss   CLOCK_PIN
    goto    waitForClockHigh
    return
    
; ------------------------------------------------------------------------------
; waitForClockLow - loops until the CLOCK input pin is low
; ------------------------------------------------------------------------------
waitForClockLow:
    btfsc   CLOCK_PIN
    goto    waitForClockLow
    return
 
; ------------------------------------------------------------------------------
; pullClockDown - set the CLOCK pin to an output (value 0)
; ------------------------------------------------------------------------------
pullClockDown:
    bank1
    bcf	    CLOCK_IO
    bank0
    bcf	    CLOCK_PIN
    return
  
; ------------------------------------------------------------------------------
; pullClockUp - set the CLOCK pin to an input (floating/pulled high)
; ------------------------------------------------------------------------------
pullClockUp:
releaseClock:
    bank1
    bsf	    CLOCK_IO
    bank0
    return
    
; ------------------------------------------------------------------------------
; pullDataDown - set the DATA pin to an output (value 0)
; ------------------------------------------------------------------------------
pullDataDown:
    bank1
    bcf	    DATA_IO
    bank0
    bcf	    DATA_PIN
    return

; ------------------------------------------------------------------------------
; pullDataUp - set the DATA pin to an input (floating/pulled high)
; ------------------------------------------------------------------------------
pullDataUp:
releaseData:
    bank1
    bsf	    DATA_IO
    bank0
    return
 
; ------------------------------------------------------------------------------
; longDelay - a long delay...
; ------------------------------------------------------------------------------
longDelay:
    movlw   255
    call    delayUs
    movlw   255
    call    delayUs
    movlw   255
    call    delayUs
    movlw   255
    call    delayUs
    movlw   255
    call    delayUs
    return
  
; ------------------------------------------------------------------------------
; delayUs - delay a number of microseconds
; ------------------------------------------------------------------------------
; Inputs: W - number of microseconds
; ------------------------------------------------------------------------------
delayUs:
    movwf   delay_us
    
delayUs1:
    movlw   DELAY_US_COUNT
    movwf   delay_us_counter
    
delayUs2:
    decfsz  delay_us_counter,f
    goto    delayUs2
    decfsz  delay_us,f
    goto    delayUs1
    return
  
END resetVec

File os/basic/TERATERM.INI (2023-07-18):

[BG]
; Use Eterm look-feel Background extension (on/off)
BGEnable=off

; Use AlphaBlend API (on/off)
BGUseAlphaBlendAPI=on

; Susie plugin path
BGSPIPath=plugin

; Fast window sizing/moving
BGFastSizeMove=on

; Flickerless window moving
BGFlickerlessMove=on

; If HideTitle=on and BGNoFrame=on, use window without frame
; you can resize window with Alt + Shift + LeftDrag
BGNoFrame=on

; wildcard => random select
BGThemeFile=theme\*.ini

; This option ignores the BGThemeFile in any case. When the option is on,
; the wallpaper image does not be mixed with theme file image.
BGIgnoreThemeFile=off


[Tera Term]
;	Tera Term version number
Version=4.106

;	Language (English/Japanese/Russian/Korean/UTF-8)
Language=UTF-8

; User interface language file that includes message strings.
; Tera Term uses built-in English message when the file or message is not found.
UILanguageFile=lang\Default.lng

; Connecting timeout value(per seconds). No action if the value is zero.
; Connecting socket could be canceled after the value timeout if the value is greater than zero.
; The default value is zero(depends on Windows TCP/IP stack implementation).
ConnectingTimeout=0

; pasting string by clicking mouse right button disabled
DisablePasteMouseRButton=off

; pasting string by clicking mouse middle button disabled
DisablePasteMouseMButton=on

; confirm pasting string by clicking mouse right button
ConfirmPasteMouseRButton=off

; confirm changing clipboard string by clicking mouse right button
ConfirmChangePaste=on
ConfirmChangePasteCR=on
PasteDialogSize=448,303
ConfirmChangePasteStringFile=

; Scroll out the current buffer when the clear screen does.
ScrollWindowClearScreen=on

; Reset scrollback on display activity
AutoScrollOnlyInBottomLine=on

; Starting the selection only by a left button.
SelectOnlyByLButton=on

; New connection by Alt-N Accelerator key
AcceleratorNewConnection=on

; Duplicate session by Alt-D Accelerator key disabled
DisableAcceleratorDuplicateSession=off

; Cygwin connection by Alt-G Accelerator key
AcceleratorCygwinConnection=on

; Send break by Alt-B Accelerator key disabled
DisableAcceleratorSendBreak=off

; New connection Menu disabled
DisableMenuNewConnection=off

; Duplicate session Menu disabled
DisableMenuDuplicateSession=off

; Send break Menu disabled
DisableMenuSendBreak=off

;	ANSI color definition (in the case FullColor=on)
;	* UseTextColor should be off, or the background and foreground color of
;	  VTColor are assigned to color-number 0 and 7 respectively, even if
;	  they are specified in ANSIColor.
;	* ANSIColor is a set of 4 values that are color-number(0--15),
;	  red-value(0--255), green-value(0--255) and blue-value(0--255).
ANSIColor=0,0,0,0, 1,255,0,0, 2,0,255,0, 3,255,255,0, 4,128,128,255, 5,255,0,255, 6,0,255,255, 7,255,255,255, 8,64,64,64, 9,192,0,0, 10,0,192,0, 11,192,192,0, 12,64,64,192, 13,192,0,192, 14,0,192,192, 15,192,192,192
; xterm
; ANSIColor=0,0,0,0, 1,255,0,0, 2,0,255,0, 3,255,255,0, 4,92,92,255, 5,255,0,255, 6,0,255,255, 7,255,255,255, 8,127,127,127, 9,205,0,0, 10,0,205,0, 11,205,205,0, 12,0,0,238, 13,205,0,205, 14,0,205,205, 15,229,229,229
; PuTTY
;ANSIColor=0,0,0,0, 1,255,85,85, 2,85,255,85, 3,255,255,85, 4,85,85,255, 5,255,85,255, 6,85,255,255, 7,255,255,255, 8,85,85,85, 9,187,0,0, 10,0,187,0, 11,187,187,0, 12,0,0,187, 13,187,0,187, 14,0,187,187, 15,187,187,187
; Tera Term Pro 2.3
;ANSIColor=0,0,0,0, 1,255,0,0, 2,0,255,0, 3,255,255,0, 4,0,0,255, 5,255,0,255, 6,0,255,255, 7,255,255,255, 8,128,128,128, 9,128,0,0, 10,0,128,0, 11,128,128,0, 12,0,0,128, 13,128,0,128, 14,0,128,128, 15,192,192,192
; Solarized (http://ethanschoonover.com/solarized)
;ANSIColor=0,7,54,66, 1,203,75,22, 2,88,110,117, 3,101,123,131, 4,131,148,150, 5,108,113,196, 6,147,161,161, 7,253,246,227, 8,0,43,54, 9,220,50,47, 10,133,153,0, 11,181,137,0, 12,38,139,210, 13,211,54,130, 14,42,161,152, 15,238,232,213
; Windows console new scheme (https://blogs.msdn.microsoft.com/commandline/2017/08/02/updating-the-windows-console-colors)
;ANSIColor=0,12,12,12, 1,231,72,86, 2,22,198,12, 3,249,241,165, 4,59,120,255, 5,180,0,158, 6,97,214,214, 7,242,242,242, 8,118,118,118, 9,197,15,31, 10,19,161,14, 11,193,156,0, 12,0,55,218, 13,136,23,152, 14,58,150,221, 15,204,204,204

;	Enable continued-line copy
EnableContinuedLineCopy=on

; Mouse cursor type (arrow/ibeam/cross/hand)
MouseCursor=ibeam

; Translucent window (0 - 255: transparency value)
AlphaBlend=255
AlphaBlendActive=255

; Cygwin install path
CygwinDirectory=

; Viewlog Editor path
ViewlogEditor=C:\WINDOWS\notepad.exe

; Locale for Unicode
;Locale=chs
Locale=american

; CodePage for Unicode
CodePage=65001

; Background color of text uses background color of screen (on/off)
UseNormalBGColor=on

;	Port type (serial/tcpip)
Port=serial

;	Window positions
VTPos=-2147483648,-2147483648
TEKPos=-2147483648,-2147483648

;	Terminal size
TerminalSize=120,60
;	Terminal size=window size (on/off)
TermIsWin=on
;	Auto window resizing option (on/off)
AutoWinResize=off
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

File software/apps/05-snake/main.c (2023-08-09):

#include <stdint.h>
#include <stdio.h>
#include <stdbool.h>
#include <stdlib.h>
#include <string.h>

#include "vdp.h"
#include "conio.h"
#include "main.h"

uint8_t x, y, c, r, i, j = 0;

uint16_t addr = 0;
uint16_t seed = 0;
uint8_t grow = 2;
uint16_t score = 0;
uint8_t ticks = 0;
uint8_t game_speed = 12;
bool crashed = false;

uint8_t buffer[BUFFER_SIZE] = {0};
uint16_t buffer_head = 0;
uint16_t buffer_tail = 0;

struct {
    int8_t x;
    int8_t y;
    uint8_t dir;
} head;

struct {
    uint8_t x;
    uint8_t y;
} apple;

uint8_t tb[40];

void print_at_xy(uint8_t x, uint8_t y, uint8_t * s) {
        addr = 0x600 + (y*32) + x;
        do {
                *(char*)addr = *s;
                ++s;
                ++addr;
        } while (*s != 0);
}

void set_pattern_color(uint8_t pattern, uint8_t color) {
        vdp_set_write_address(pattern * 8 + VDP_COLOR_TABLE);
        for (i=0; i<8; ++i) {
                *(char*)VDP_RAM = color;
        }
}

void init_game() {
        vdp_init_g2();
        // Set all colours to grey on black.
        vdp_set_write_address(VDP_COLOR_TABLE);
        for(addr=0; addr<0x800; ++addr) {
                *(char*)VDP_RAM=0xe1;
        }

        //Set snake character colours
        set_pattern_color(head_up, 0x61);
        set_pattern_color(head_dn, 0x61);
        set_pattern_color(head_lt, 0x61);
        set_pattern_color(head_rt, 0x61);
        set_pattern_color(applechar,   0x21);
}

void print_center_y(uint8_t y, char * s) {
        uint8_t len = strlen(s);
        uint8_t x = 15-(len/2);
        print_at_xy(x,y,s);
}

void new_apple() {
        bool taken = true;
        while(taken) {
                x = (rand() % 32);
                y = (rand() % 24);
                if (vdp_read_from_screen_xy(x,y) == 0x20) {
                        taken = false;
                        apple.x = x;
                        apple.y = y;
                }
        }
        vdp_write_to_screen_xy(apple.x, apple.y, applechar);
        grow = 2;
}

uint8_t menu(void) {
        print_center_y(3, "SNAKE 6502 - V1.0");
        print_center_y(5, "BY PRODUCTION-DAVE");
        print_center_y(13,"PRESS ANY KEY TO PLAY");

        sprintf(tb, "SCORE: %d", score);
        print_center_y(7, tb);

        if (crashed == true) {
                print_center_y(23, "CRASHED");
        }

        vdp_wait();
        vdp_flush();
        seed = 0;
        do {
                c = cgetc_nw();
                ++seed;
        } while (c == 0);
        if (c == 0x1b) {
                return 0;
        } else {
                srand(seed);
                return 1;
        }
}

void new_game(void) {

        memset((uint8_t*)0x600,0x20,0x300);
        buffer_head = 0;
        buffer_tail = 0;
        head.x = 15;
        head.y = 20;
        head.dir = head_rt;
        game_speed = 8;
        ticks = 0;
        crashed = false;
        grow = 2;
        score = 0;
        new_apple();
        vdp_wait();
        vdp_flush();
}

void run(void) {
        do {
                if (ticks == game_speed) {
                        c = cgetc_nw();

                        if (c == 0x1b) {
                                crashed = true;
                                cputs("ESCAPE PRESSED");
                        } else if (c == 0xA1) {
                                if (head.dir != head_rt) head.dir = head_lt;
                        } else if (c == 0xA2) {
                                if (head.dir != head_lt) head.dir = head_rt;
                        } else if (c == 0xA3) {
                                if (head.dir != head_dn) head.dir = head_up;
                        } else if (c == 0xA4) {
                                if (head.dir != head_up) head.dir = head_dn;
                        }

                        if (head.dir == head_lt) {
                                head.x--;
                        } else if (head.dir == head_rt) {
                                head.x++;
                        } else if (head.dir == head_up) {
                                head.y--;
                        } else if (head.dir == head_dn) {
                                head.y++;
                        } else {
                                crashed = false;
                        }

                        if ( head.x < 0 || head.x > 31 ) {
                                crashed = true;
                                cputs("X Boundary\n");
                        }
                        if ( head.y < 0 || head.y > 23 ) {
                                crashed = true;
                                cputs("Y Boundary\n");
                        }

                        r = vdp_read_from_screen_xy(head.x, head.y);
                        if (r == applechar) {
                                score += 5;
                                new_apple();
                        } else if (r != 0x20) {
                                crashed = true;
                                cputs("HIT TAIL\n");
                        }
                        if (crashed == false) {
                                vdp_write_to_screen_xy(head.x, head.y, head.dir);
                                if (buffer_head > BUFFER_SIZE) {
                                        buffer_head = 0;
                                }
                                buffer[buffer_head] = head.x;
                                buffer[buffer_head+1] = head.y;
                                buffer_head += 2;

                                if (grow > 0) {
                                        grow --;
                                } else {
                                        vdp_write_to_screen_xy(buffer[buffer_tail], buffer[buffer_tail+1], 0x20);
                                        buffer_tail += 2;
                                        if (buffer_tail > BUFFER_SIZE) {
                                                buffer_tail = 0;
                                        }
                                }
                                vdp_wait();
                                vdp_flush();
                                ticks = 0;
                        }
                } else {
                        vdp_wait();
                        ticks ++;
                }

        } while (crashed == false);
}

void main(void) {
        init_game();
        sprintf(tb, "Free memory: %d\n", _heapmemavail());
        cputs(tb);
        while(1) {
                if( !menu() ) {
                        break;
                } else {
                        new_game();
                        run();
                }
        }
}

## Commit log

2023-07-08 initial import
    [6502-retro-CuBottom.gbr, 6502-retro-CuIn1.gbr, 6502-retro-CuIn2.gbr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]
2023-07-09 progress on rom examples
    [6502-retro-rom.cfg]
2023-07-12 remove old hardware
    [6502-retro-CuBottom.gbr, 6502-retro-CuIn1.gbr, 6502-retro-CuIn2.gbr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]
2023-07-18 refresh from be6502
    [6502-retro-load.cfg, 6502-retro-rom.cfg, 6502-retro.kicad_sch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]
2023-07-21 working-os without VDP or Audio
    [firmware.cfg, firmware.load.cfg]
2023-07-24 OS will replace software
    [6502-retro-f18a.kicad_pcb, 6502-retro-f18a.kicad_sch, 6502-retro-f18a.sch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]
2023-07-25 updated hardware
    [6502-retro-io.kicad_pcb, 6502-retro-io.kicad_sch, 6502-retro.kicad_sch]
2023-07-25 removed software directory
    [firmware.cfg, firmware.load.cfg]
2023-07-31 add c software
    [ram.cfg, rom.cfg]
2023-07-31 Add C code
    [ram.cfg, rom.cfg]
2023-08-08 More mature OS with more mature C support. Snake in C!
    [firmware.cfg, firmware.load.cfg, ram.cfg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]
2023-08-08 update to readme - warning about J1 slot location
2023-08-09 remove c
    [ram.cfg, rom.cfg]
2023-08-15 CTRL+C, blinky, and keybard basic
    [ram.cfg, rom.cfg]
